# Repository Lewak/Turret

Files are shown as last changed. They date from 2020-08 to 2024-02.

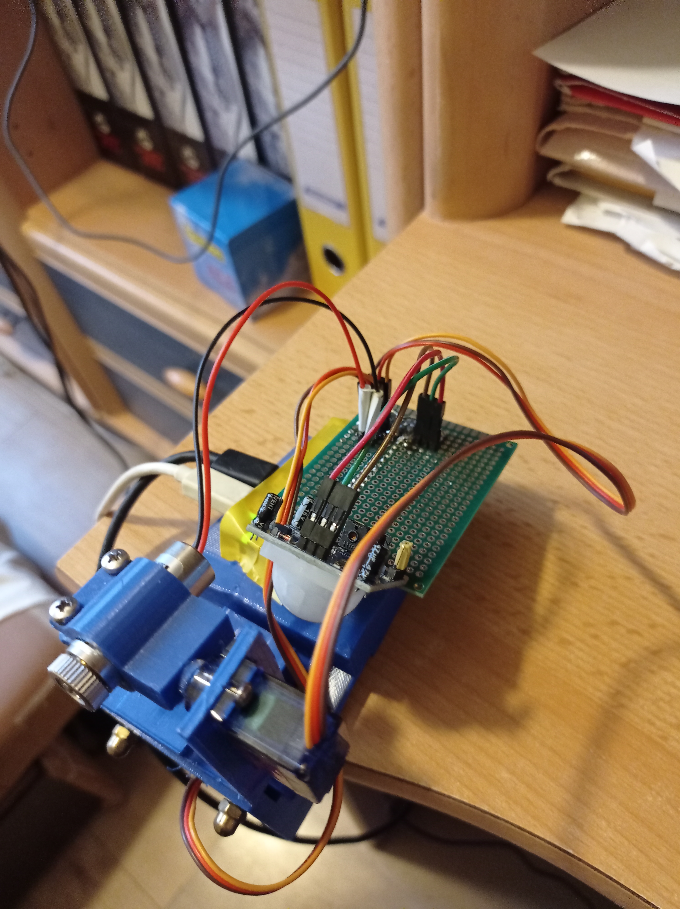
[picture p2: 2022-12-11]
Schemas/raspberry + peripherals assembly.jpg

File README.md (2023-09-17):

# INSTRUKCJA
## vol.1 RASPBERRY JAKO ETHERNET GADGET
1. Podłączyć raspberry za pomocą kabla USB (DO PORTU USBIN nie USB POWER!)
2. Sprawdzić w menadżerze urządzeń czy jest wykrywany jako usb ethernet gadget. Jak tak, przejść do kroku 6
3. Pobrać sterownik usb ethernet gadget (Acer Incorporated. - Other hardware - USB Ethernet/RNDIS Gadget) stąd: 
	https://www.catalog.update.microsoft.com/Search.aspx?q=USB%20RNDIS%20Gadget
4. Wypakować pobrane archiwum, kliknąć ppm na RNDIS.inf i wybrać install
5. Wejść w menadżer urządzeń, odłączyć i podłączyć RPi, żeby zobaczyć jako co jest wykrywane - może to być np. port COM. Wybrać to urządzenie, 
	update driver, browse my computer, let me pick from a list.., have disk, wybrać RNDIS.inf. Sprawdzić czy teraz jest wykrywany, 
	jak nie to można się popłakać i zawołać mazura.
6. Spróbować połączyć się za pomocą komendy ssh, adres IP można zdobyć poprzez ipconfig albo spróbować użyć: ssh pi@raspberrypi.local (hasło to raspberry)
7. Mozna zainstalowac sterownik Bonjour, by moc używać nazwy .local w IDE (możliwe że niepotrzebne)
8. By uruchomić internet na raspberry. Należy wejść w windows panel sterownia, network and sharing -> change adapter settings
	(old: ethernet settings -> change adapter settings) 
	wybrać AKTUALNE DZIAŁAJĄCE POŁĄCZENIE INTERNETOWE (NIE IP RASPBERRY) -> properties -> settings ->sharing -> w obu checkboxach zaznaczyć allow 
	i wybrać Ethernet gadget RPi
9. Powinno działać 

## vol.2 DŹWIĘK I IO
1. Plik do dźwięku znajduje sie w: /etc/asound.conf
2. Plik autostartu z komendami uruchamianymi przy boocie to /etc/rc.local (komenda sudo pigpiod -t 0)
		
## vol.3 PROCEDURA URUCHAMIANIA TURRETA
1. Wpisać login i password w deployment w file->settings->deployment: login:pi hasło: raspberry
2. Prawy przycisk na pliki programu i deployment->send to raspberrypi

## vol.4 PROCEDURA URUCHAMIANIA PŁYKI ENDERA
1. Zainstalować środowisko kombatybilne z Arduino (np Visual Studio Code z pluginem). 
2. Zainstalować boardy Sanguino
3. Przed uploadem ustawić port COM, ustawić płytkę Sanguino z procesorem Atmega1284 16Mhz.

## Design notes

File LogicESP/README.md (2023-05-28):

# Konfiguracja środowiska
1. Zainstaluj sterownik: https://www.silabs.com/developers/usb-to-uart-bridge-vcp-drivers?tab=downloads, zakładka CP210x VCP Windows
2. Podłącz płytkę przez USB C
3. W Visual Studio Code zainstaluj plugin "Arduino". Za pomocą `Ctrl + Shift + P` wywołuj komendy do komunikacji z płytką.
4. Arduino: Board Manager -> Additional URLs -> Add -> wpisz https://raw.githubusercontent.com/espressif/arduino-esp32/gh-pages/package_esp32_index.json i zatwierdź -> wyłącz okno Board Manager
5. Arduino: Board Config -> ESP32 Dev Module (esp32), Core Debug Level: Verbose
6. Arduino: Select Serial Port -> COM4

# Podłączanie układu
Powinno być tak:

lol

Uwaga, przed podłączeniem zasilania upewnić się, że:
+ nie ma zwarć
+ napięcia są dobrze podłączone, tj. 12V, 5V i 3.3V idą dokładnie tam gdzie powinny i nigdzie indziej
+ plusy i minusy nie są odwrotnie
+ najpierw należy podłączyć zasilanie do komputera, a potem zasilanie zewnętrzne 12V

W trakcie pracy:
+ Nie wolno odłączać silników ani jakichkolwiek innych komponentów
+ Jakiekolwiek modyfikacje powinny być wykonywane po odłączeniu zasilania

# Uruchamianie kodu
1. Arduino: Upload
2. Gdy płytka jest zorientowana tak, że kabel USB wchodzi do niej od dołu, na prawo od kabla znajduje się przycisk flash, a na lewo reset. Gdy w konsoli output stanie na "Serial port COM4", wciśnij i przytrzymaj flash, następnie wciśnij reset, puść reset, puść flash (kolejność ma znaczenie). Jeśli upload się nie powiód:
    + może być zły port - powinno być COM4
    + warto odłączyć usb od komputera i wpiąć ponownie

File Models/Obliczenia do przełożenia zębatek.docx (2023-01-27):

Byłoby dobrze, gdyby ramię było w stanie skręcić o α=90^(∘) w ciągu t=0.25 s . Oznacza to, że musi mieć takie przyspieszenie kątowe ϵ , że w czasie t przez połowę czasu będzie przyspieszać, przez drugą połowę czasu zwalniać, a w łącznym czasie przebędzie kąt π/2 , czyli α=1/2∙t∙1/2ϵt=1/4ϵt^2 , stąd ϵ=(4α)/(t^2) .

Aby obliczyć moment bezwładności ramion wokół osi pionowej (ruch lewo-prawo) przyjmujemy, że każde z ramion można przybliżyć jako masę punktową m=3 kg zawieszoną w odległości d=25 cm od osi, stąd I_(vertical) =2∙1/2∙m∙d^2 =md^2 .

Moment bezwładności wokół osi poziomej (ruch góra-dół) przybliżamy za pomocą dwóch cylindrów o masie m=3 kg i promieniu r=25 cm obracających się wokół swojej osi, czyli również I_(horizontal) =2∙1/2∙m∙r^2 =mr^2 . Ponieważ ze względu na gabaryty wieżyczki d=r , mamy I=I_(horizontal) =I_(vertical) .

Moment siły wynosi więc M_(arms) =Iϵ=md^2 ∙(4α)/(t^2) .

Moment obrotowy silnika Nema 17 wynosi M_(nema) =2000 gcm=2000∙g∙10^(-5) Nm=0.1962 Nm .

Przełożenie zębatek musi więc wynosić na obu osiach:

(M_(arms))/(M_(nema))=3kg∙(0.25m)^2 ∙4∙π/2∙1/((0.25s)^2)∙1/(0.1962 Nm)=96

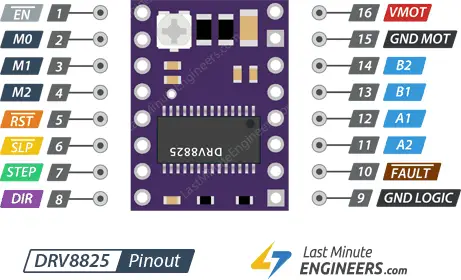
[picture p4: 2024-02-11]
Schemas/Pinout - DRV8825.png

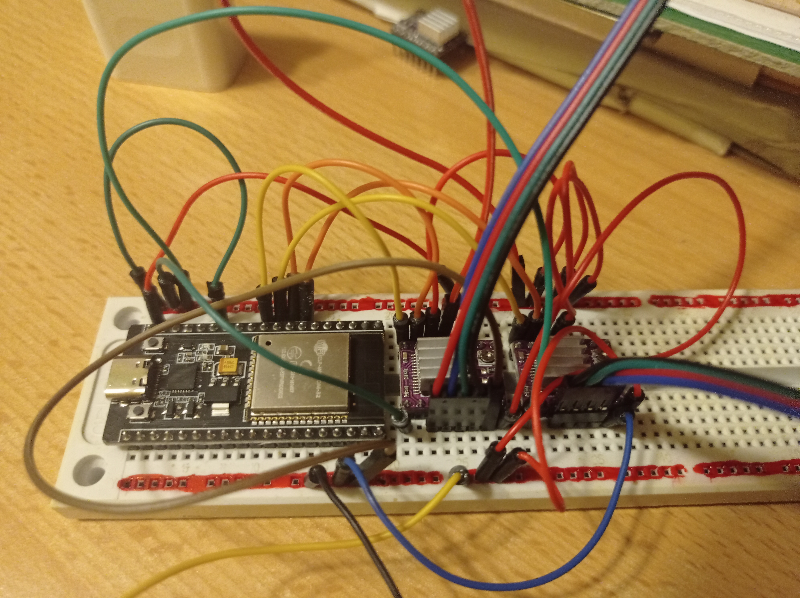
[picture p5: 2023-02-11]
Schemas/esp + 2 steppers.jpg

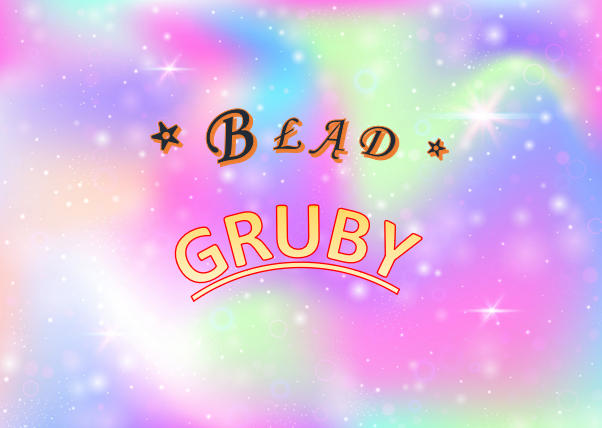
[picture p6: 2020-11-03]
Schemas/Błąd Gruby.png

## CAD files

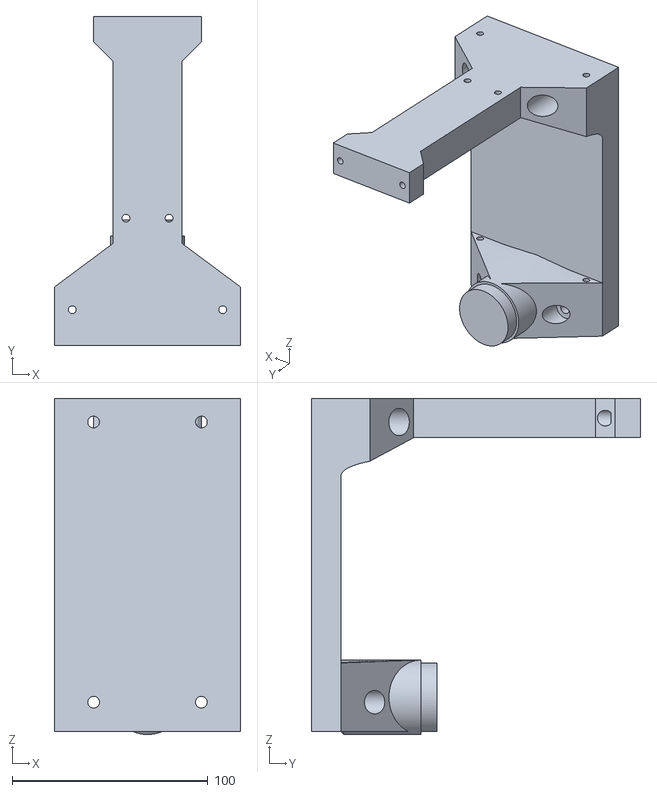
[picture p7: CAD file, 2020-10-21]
Models/turret_assembly/Design Accelerator/main_stand_lower_half.stl
95.0 x 168.0 x 171.5

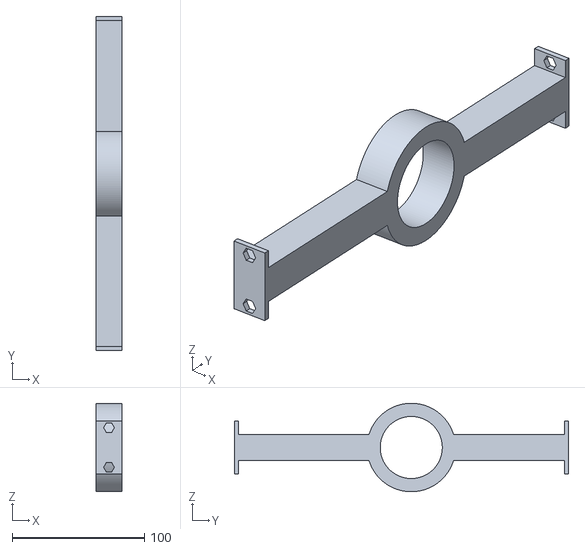
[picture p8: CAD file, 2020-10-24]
Models/turret_assembly/Design Accelerator/pylon.stl
20.0 x 253.0 x 67.0

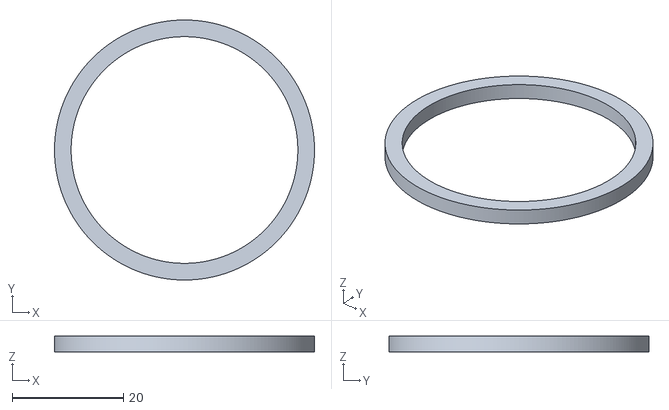
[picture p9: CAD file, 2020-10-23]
Models/turret_assembly/Design Accelerator/Swash_distance.stl
46.8 x 46.8 x 2.80

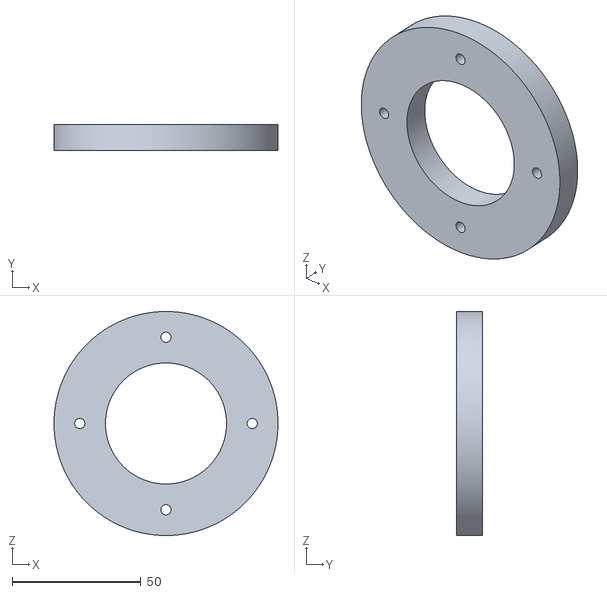
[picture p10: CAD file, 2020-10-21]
Models/turret_assembly/Design Accelerator/horizontal_lower_bearing_holder.stl
87.0 x 10.0 x 87.0

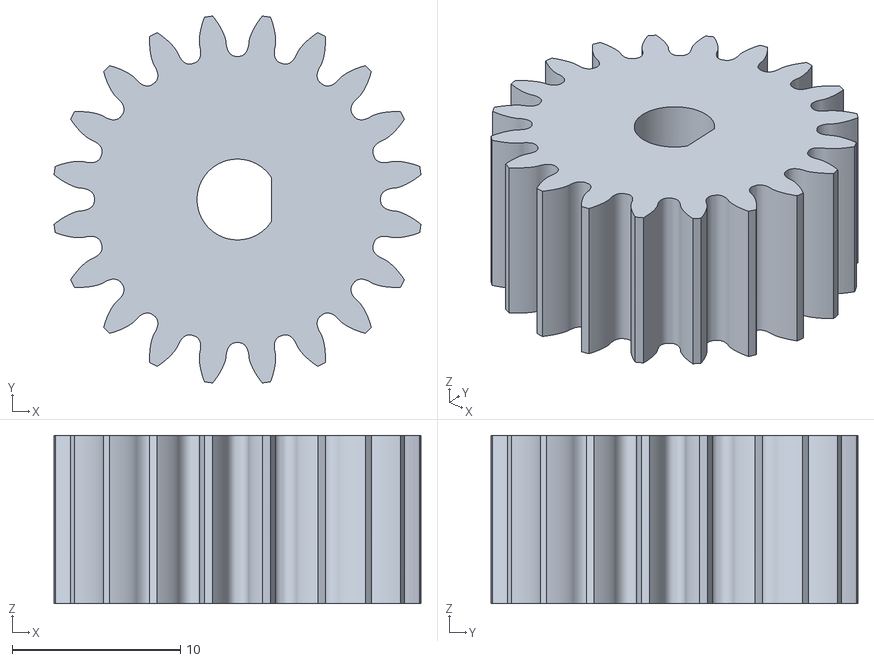
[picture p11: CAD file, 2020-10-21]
Models/turret_assembly/Design Accelerator/vertical_axis_small_gear.stl
21.8 x 21.8 x 10.0

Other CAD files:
Models/Gimbal.dwg
Models/camera_holder.ipt
Models/pylon-hal-bearing-holder.ipt
Models/pylon_actuator_holder.ipt
Models/pylon_actuator_holder_jaw.ipt
Models/raspberry_holder.ipt
Models/servo_holder.ipt
Models/step_motor/Flecha 17HS4401 v3.ipt
Models/step_motor/INF TECNICA 2 v1.ipt
Models/step_motor/Nema 17 Motor a Pasos 17HS4401.iam
Models/step_motor/Part10.ipt
Models/step_motor/Pines v2.ipt
Models/step_motor/Tornillo v2.ipt
Models/turret_assembly.iam
Models/turret_assembly/Design Accelerator/Spur Gear11.ipt
Models/turret_assembly/Design Accelerator/Spur Gear21.ipt
Models/turret_assembly/Design Accelerator/Spur Gears1.iam
Models/turret_assembly/Design Accelerator/Swash_distance.ipt
Models/turret_assembly/Design Accelerator/big_actuator_holder.ipt
Models/turret_assembly/Design Accelerator/horizontal_axis_big_gear.ipt
Models/turret_assembly/Design Accelerator/horizontal_axis_hal_gearr.ipt
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

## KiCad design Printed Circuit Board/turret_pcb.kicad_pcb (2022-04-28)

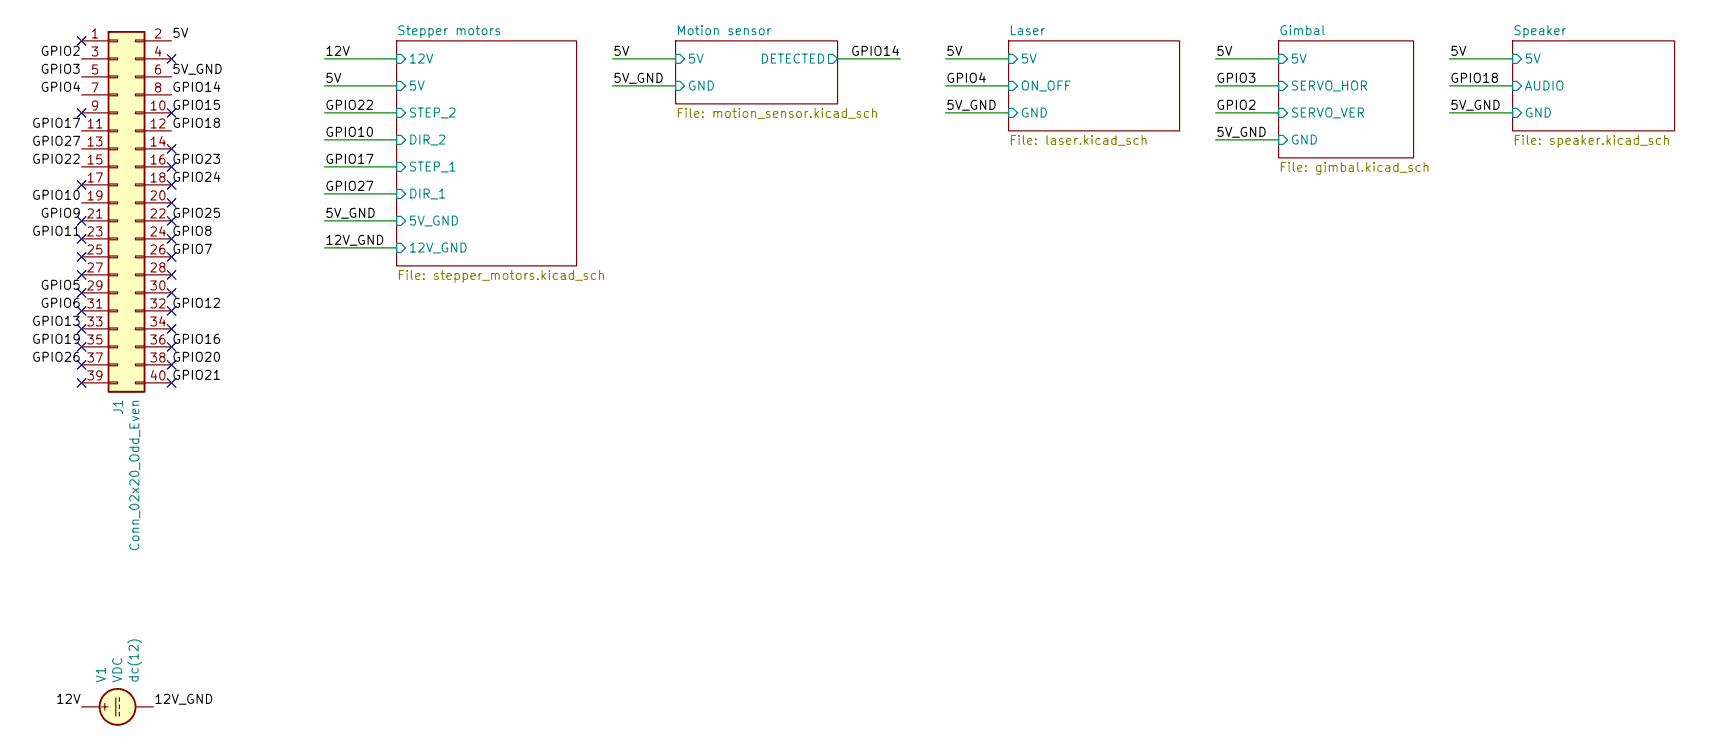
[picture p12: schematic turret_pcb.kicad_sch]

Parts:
J1: Conn_02x20_Odd_Even; PinSocket_2x20_P2.54mm_Vertical
V1: VDC; Banana_Jack_2Pin

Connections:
/5V: J1.2; also elsewhere on the board
/5V_GND: J1.6; also elsewhere on the board
/12V: V1.1; also elsewhere on the board
/12V_GND: V1.2; also elsewhere on the board
/GPIO2: J1.3; also elsewhere on the board
/GPIO3: J1.5; also elsewhere on the board
/GPIO4: J1.7; also elsewhere on the board
/GPIO5: J1.29
/GPIO6: J1.31
/GPIO7: J1.26
/GPIO8: J1.24
/GPIO9: J1.21
/GPIO10: J1.19; also elsewhere on the board
/GPIO11: J1.23
/GPIO12: J1.32
/GPIO13: J1.33
/GPIO14: J1.8; also elsewhere on the board
/GPIO15: J1.10
/GPIO16: J1.36
/GPIO17: J1.11; also elsewhere on the board
/GPIO18: J1.12; also elsewhere on the board
/GPIO19: J1.35
/GPIO20: J1.38
/GPIO21: J1.40
/GPIO22: J1.15; also elsewhere on the board
/GPIO23: J1.16
/GPIO24: J1.18
/GPIO25: J1.22
/GPIO26: J1.37
/GPIO27: J1.13; also elsewhere on the board

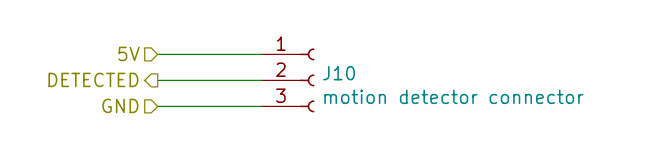
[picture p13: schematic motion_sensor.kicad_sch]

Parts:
J10: motion detector connector; PinHeader_1x03_P2.54mm_Vertical

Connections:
/5V: J10.1; also elsewhere on the board
/5V_GND: J10.3; also elsewhere on the board
/GPIO14: J10.2; also elsewhere on the board

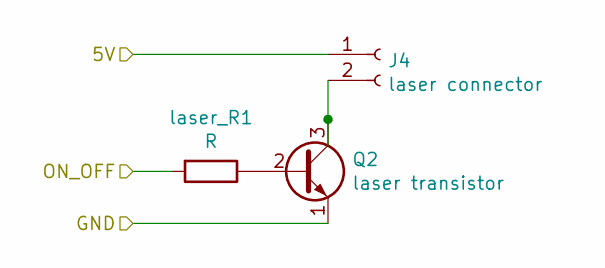
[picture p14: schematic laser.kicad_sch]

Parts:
J4: laser connector; PinHeader_1x02_P2.54mm_Vertical
Q2: laser transistor; TO-39-3
laser_R1: R; R_1206_3216Metric

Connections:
/5V: J4.1; also elsewhere on the board
/5V_GND: Q2.1 (E); also elsewhere on the board
/GPIO4: laser_R1.2; also elsewhere on the board
unnamed: J4.2, Q2.3 (C)
unnamed: Q2.2 (B), laser_R1.1

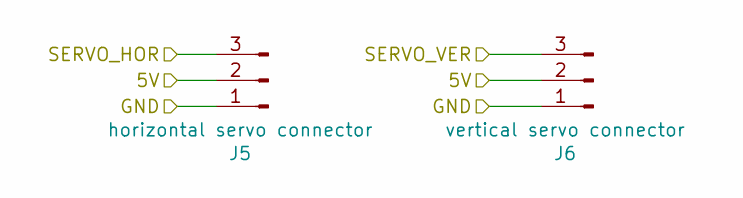
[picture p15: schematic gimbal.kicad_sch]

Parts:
J5: horizontal servo connector; PinHeader_1x03_P2.54mm_Vertical
J6: vertical servo connector; PinHeader_1x03_P2.54mm_Vertical

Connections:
/5V: J5.2, J6.2; also elsewhere on the board
/5V_GND: J5.1, J6.1; also elsewhere on the board
/GPIO2: J6.3; also elsewhere on the board
/GPIO3: J5.3; also elsewhere on the board

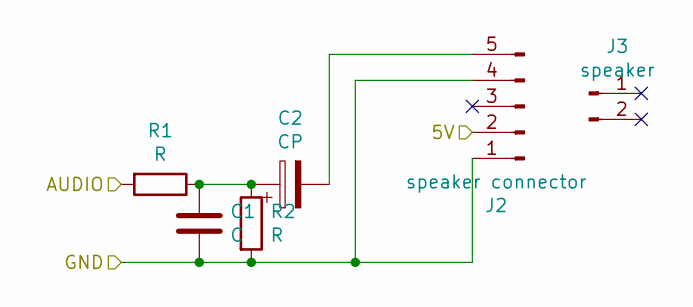
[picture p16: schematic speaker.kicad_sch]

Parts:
C1: C; C_Disc_D4.7mm_W2.5mm_P5.00mm
C2: CP; C_Radial_D6.3mm_H5.0mm_P2.50mm
J2: speaker connector; PinHeader_1x05_P2.54mm_Vertical
J3: speaker; PinHeader_1x02_P2.54mm_Vertical
R1: R; R_1206_3216Metric_Pad1.30x1.75mm_HandSolder
R2: R; R_1206_3216Metric

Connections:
/5V: J2.2; also elsewhere on the board
/5V_GND: C1.2, J2.1, J2.4, R2.2; also elsewhere on the board
/GPIO18: R1.2; also elsewhere on the board
unnamed: C1.1, C2.1, R1.1, R2.1
unnamed: C2.2, J2.5

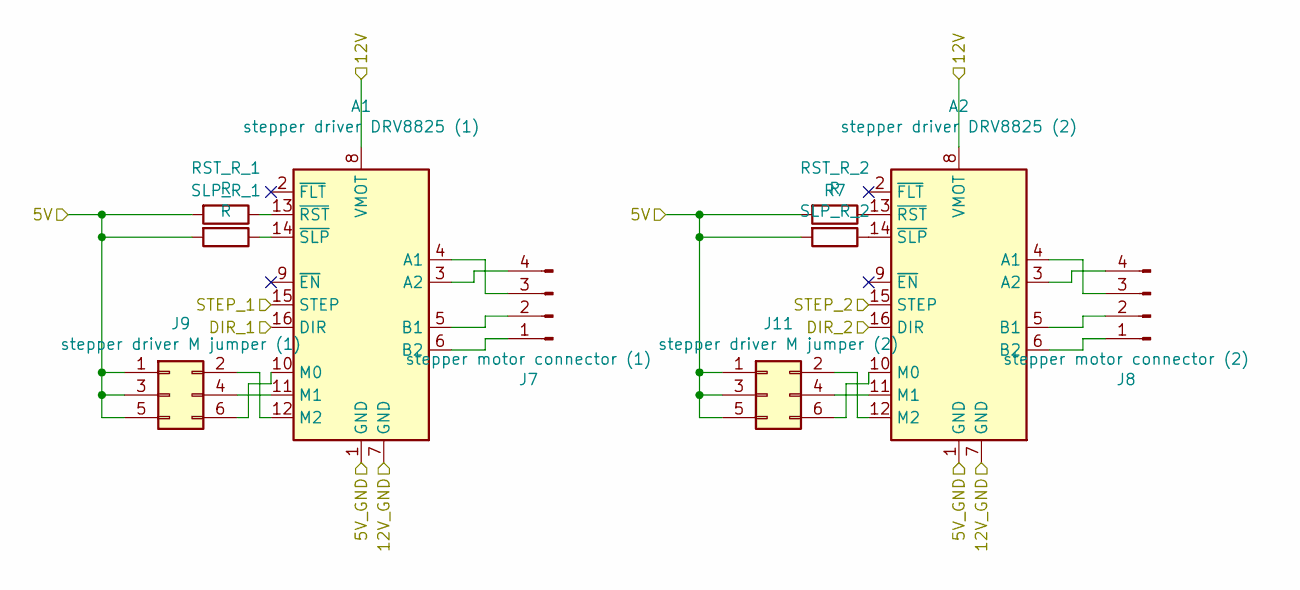
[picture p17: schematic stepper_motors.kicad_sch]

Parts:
A1: stepper driver DRV8825 (1); Pololu_Breakout-16_15.2x20.3mm
A2: stepper driver DRV8825 (2); Pololu_Breakout-16_15.2x20.3mm
J7: stepper motor connector (1); PinHeader_1x04_P2.54mm_Vertical
J8: stepper motor connector (2); PinHeader_1x04_P2.54mm_Vertical
J9: stepper driver M jumper (1); PinSocket_2x03_P2.54mm_Vertical
J11: stepper driver M jumper (2); PinSocket_2x03_P2.54mm_Vertical
R7: SLP_R_2; R_1206_3216Metric
RST_R_1, RST_R_2: R; R_1206_3216Metric
SLP_R_1: R; R_1206_3216Metric

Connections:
/5V: J9.1, J9.3, J9.5, J11.1, J11.3, J11.5, R7.2, RST_R_1.2, RST_R_2.2, SLP_R_1.2; also elsewhere on the board
/5V_GND: A1.1 (GND), A2.1 (GND); also elsewhere on the board
/12V: A1.8 (VMOT), A2.8 (VMOT); also elsewhere on the board
/12V_GND: A1.7 (GND), A2.7 (GND); also elsewhere on the board
/GPIO10: A2.16 (DIR); also elsewhere on the board
/GPIO17: A1.15 (STEP); also elsewhere on the board
/GPIO22: A2.15 (STEP); also elsewhere on the board
/GPIO27: A1.16 (DIR); also elsewhere on the board
unnamed: A1.3 (A2), J7.4
unnamed: A1.4 (A1), J7.3
unnamed: A1.5 (B1), J7.2
unnamed: A1.6 (B2), J7.1
unnamed: A1.10 (M0), J9.6
unnamed: A1.11 (M1), J9.4
unnamed: A1.12 (M2), J9.2
unnamed: A1.13 (~RST), RST_R_1.1
unnamed: A1.14 (~SLP), SLP_R_1.1
unnamed: A2.3 (A2), J8.4
unnamed: A2.4 (A1), J8.3
unnamed: A2.5 (B1), J8.2
unnamed: A2.6 (B2), J8.1
unnamed: A2.10 (M0), J11.6
unnamed: A2.11 (M1), J11.4
unnamed: A2.12 (M2), J11.2
unnamed: A2.13 (~RST), RST_R_2.1
unnamed: A2.14 (~SLP), R7.1

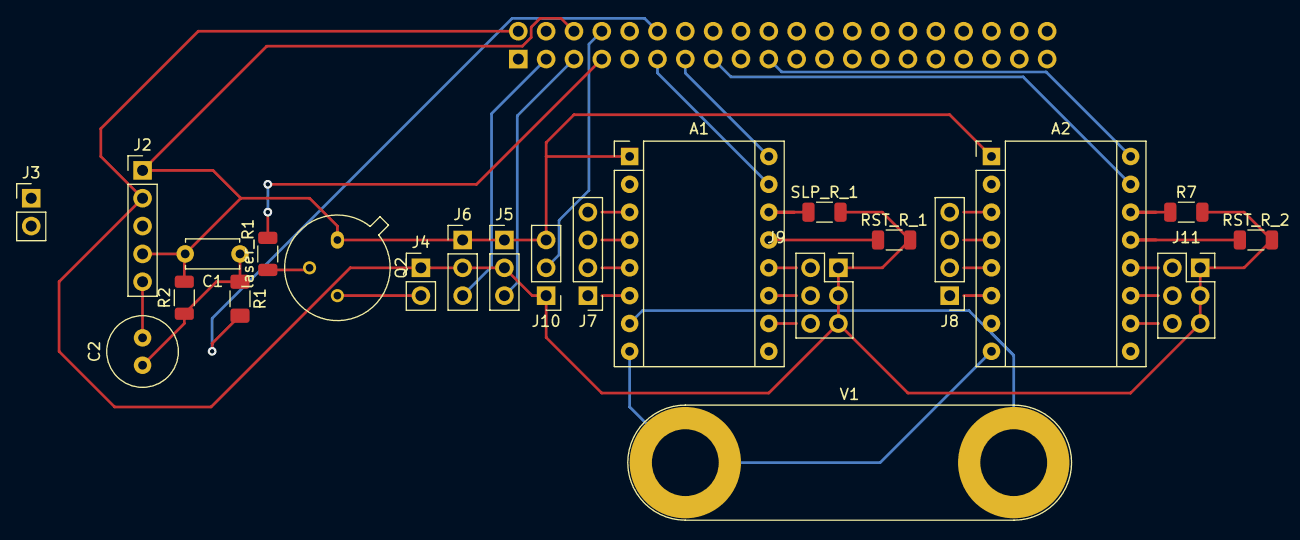
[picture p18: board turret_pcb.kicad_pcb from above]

Board: 2 copper layers, 24 parts (1 on the bottom side), 35 nets.

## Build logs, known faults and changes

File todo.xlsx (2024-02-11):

Silniki krokowe | Skonfigurować nową płytkę arduino+drv8825 zamiast ender3
 | Potestować konfigurację z czujnikiem Halla (coś w stylu PID)
 | Poeksperymentować z trybami pracy driverów w silnikach
 | Podłączyć esp + raspberry przez Serial
 | Programowanie | ESP: cleanup kodu, użycie hala i dwóch silników Raspberry: uzgodnić układ współrzędnych (środek, orientacja); refactor pathGenerator; klasa do obsługi arm-gimbala
 | Przelutować pajęczaka na płytkę
 | Przeprojektować model w inventorze, by obsługiwał silniki i Halla | zębatki wokół osi pionowej się rozjechały
 |  | constrainy na obrót wokół osi pionowej są zrąbane
 |  | czujniki hala na oś pionową i poziomą
 |  | miejsce na przewody ciśnieniowe
 |  | duża zębatki mogą być ucięte do połowy (180* ruchu zamiast 360*)
 | Przełożenie zębatek wymaga aktualizacji | nie bardzo wiadomo jakiego przełożenia użyć - do sprawdzenia z realnym obciążeniem
Lutowanie | Naprawić potencjometr w lutownicy
Audio | Uszkodzony układ audio u Piotera
 | Użyć nowych odzyskanych głośników
 | Dodać wzmacniacz | później
 | Dodać głośnik basowy do pary | później
Siłowniki i hydrostatyka
Kamera
Działka
Obudowa | PCB integrujące wszystkie płytki i komponenty
 | miejsce na płytki w modelu
 | Przemyślenie prowadzenia kabli między komponentami
 | Zrobić dystans na silnik poziomy
Naprawy | Naprawić/przeprojektować mechanizm celowania laserem.

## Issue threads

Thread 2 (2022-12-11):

Redesign spur gears to accomodate different reduction ratios

Lewak, 2022-12-11:
Current reduction ratio (1:10) is definitely too much. It would be a good idead to design alternate version of these parts. Modular/parametric design would be prefered here

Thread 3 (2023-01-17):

Repair of main soldering iron used in this project.

Lewak, 2023-01-17:
It came to our attention, that the soldering iron that our main electronic engineer uses, is in simple words, "fucked" (PL. "zjebana"). To further our attempts at assembling prototype boards, it needs to be fixed. Our enginner will need another soldering iron to fix the broken one. Let's hope it doesn't became a while (true) loop if this second soldering iron breaks.

boberrs, 2023-01-17:
Please forward the issue to IT-Support team, they should get us new equipment delivered and ready to go. Changing status to "invalid", our technicians need not to be bothered by malfunctioning devices.

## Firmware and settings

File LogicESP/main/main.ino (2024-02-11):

#include <Arduino.h>
#include <vector>
#include <string>
#include "utils.h"
#include "hal.h"
#include "serialCommunication.h"
#include "serialCommunication1.h"
using namespace std;

#define LED 2
#define STEP_X 32
#define STEP_Y 33
#define DIR_X 25
#define DIR_Y 26
#define M0_Y 12
#define M1_Y 14
#define M2_Y 27
#define MOT_ANG_MIN_DEG 5
#define MOT_ANG_MAX_DEG 175

int positionCounter = 0; // temp
int motorSpeed = 15;
int desiredAngle = 90;

void setup()
{
    serialInit();
    serial1Init();
    halInit();
    pinMode(LED, OUTPUT);
    pinMode(M0_Y, OUTPUT);
    pinMode(M1_Y, OUTPUT);
    pinMode(M2_Y, OUTPUT);
    pinMode(STEP_X, OUTPUT);
    pinMode(STEP_Y, OUTPUT);
    pinMode(DIR_X, OUTPUT);
    pinMode(DIR_Y, OUTPUT);

    digitalWrite(DIR_X, HIGH);
    digitalWrite(DIR_Y, HIGH);
    digitalWrite(M0_Y, HIGH);
    digitalWrite(M1_Y, HIGH);
    digitalWrite(M2_Y, HIGH);
}

void loop()
{
    double angle = mockReadAngle();
    serial1Read([](string code, vector<int> parameters){
        if (code == "SET")
        {
            desiredAngle = clampValue(parameters[0], MOT_ANG_MIN_DEG, MOT_ANG_MAX_DEG);
        }
    });
       
    if ((desiredAngle < angle - 0.2) || (desiredAngle > angle + 0.2))
    {
        if (desiredAngle - angle > 0)
        {
            digitalWrite(DIR_Y, LOW);
            positionCounter++;
        }
        else
        {
            digitalWrite(DIR_Y, HIGH);
            positionCounter--;
        }
        digitalWrite(STEP_X, HIGH);
        digitalWrite(STEP_Y, HIGH);
        delayMicroseconds(motorSpeed);
        digitalWrite(STEP_X, LOW);
        digitalWrite(STEP_Y, LOW);
        delayMicroseconds(motorSpeed);
    }
}

double mockReadAngle()
{
    float gearRatio = 10;
    float stepsPerRevolution = 200;
    float microsteps = 32;
    return positionCounter / gearRatio * (360.0 / (stepsPerRevolution * microsteps)) + 90;
}

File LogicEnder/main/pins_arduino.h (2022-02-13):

// ATMEL ATMEGA644/ATMEGA1284 / SANGUINO
//
//                        +---\/---+
//            (D 0) PB0  1|        |40  PA0 (AI 0 / D31)
//            (D 1) PB1  2|        |39  PA1 (AI 1 / D30)
//       INT2 (D 2) PB2  3|        |38  PA2 (AI 2 / D29)
//        PWM (D 3) PB3  4|        |37  PA3 (AI 3 / D28)
//     SS PWM (D 4) PB4  5|        |36  PA4 (AI 4 / D27)
//       MOSI (D 5) PB5  6|        |35  PA5 (AI 5 / D26)
//       MISO (D 6) PB6  7|        |34  PA6 (AI 6 / D25)
//        SCK (D 7) PB7  8|        |33  PA7 (AI 7 / D24)
//                  RST  9|        |32  AREF
//                  VCC 10|        |31  GND
//                  GND 11|        |30  AVCC
//                XTAL2 12|        |29  PC7 (D 23)
//                XTAL1 13|        |28  PC6 (D 22)
//       RX0 (D 8)  PD0 14|        |27  PC5 (D 21) TDI
//       TX0 (D 9)  PD1 15|        |26  PC4 (D 20) TDO
//  INT0 RX1 (D 10) PD2 16|        |25  PC3 (D 19) TMS
//  INT1 TX1 (D 11) PD3 17|        |24  PC2 (D 18) TCK
//       PWM (D 12) PD4 18|        |23  PC1 (D 17) SDA
//       PWM (D 13) PD5 19|        |22  PC0 (D 16) SCL
//       PWM (D 14) PD6 20|        |21  PD7 (D 15) PWM
//                        +--------+

#ifndef pins_arduino_h
#define pins_arduino_h

#define PA0 (31)
#define PA1 (30)
#define PA2 (29)
#define PA3 (28)
#define PA4 (27)
#define PA5 (26)
#define PA6 (25)
#define PA7 (24)

#define PB0 (0)
#define PB1 (1)
#define PB2 (2)
#define PB3 (3)
#define PB4 (4)
#define PB5 (5)
#define PB6 (6)
#define PB7 (7)

#define PC0 (16)
#define PC1 (17)
#define PC2 (18)
#define PC3 (19)
#define PC4 (20)
#define PC5 (21)
#define PC6 (22)
#define PC7 (23)

#define PD0 (8)
#define PD1 (9)
#define PD2 (10)
#define PD3 (11)
#define PD4 (12)
#define PD5 (13)
#define PD6 (14)
#define PD7 (15)


#define SD_SS (PA0)
#define LCD_SCK (PA1)
#define EXT_A2 (PA2)
#define LCD_CS (PA3)
#define Beeper (PA4)
#define ZENABLE (PA5)
#define BEDTEMP (PA6)
#define ENDTEMP (PA7)

#define E_DIR (PB0)
#define E_STEP (PB1)
#define Z_DIR (PB2)
#define Z_STEP (PB3)
#define FAN (PB4)
#define MOSI (PB5)
#define MISO (PB6)
#define SCLK (PB7)

#define Encoder_Button (PC0)
#define LCD_MOSI (PC1)
#define X_STOP (PC2)
#define Y_STOP (PC3)
#define Z_STOP (PC4)
#define X_DIR (PC5)
#define Y_STEP (PC6)
#define Y_DIR (PC7)

#define AIFO (PD0)
#define AOFI (PD1)
#define Encoder_A (PD2)
#define Encoder_B (PD3)
#define Hotbed (PD4)
#define Hotend (PD5)
#define XYEENABLE (PD6)
#define X_STEP (PD7)

#endif

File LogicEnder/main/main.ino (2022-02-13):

#include <AccelStepper.h>
#include <MultiStepper.h>


#include "pins_arduino.h"
#define acceleration 2000
#define deceleration 1000
#define max_speed 6000
#define full_rotation 3200
#define first_delay 80
int actual_speed = 1000;
int target_speed = 80000;

void setup() 
{
    float acc_dec_ratio = (acceleration/deceleration);

    Serial.begin(9600);
    pinMode(XYEENABLE, OUTPUT);
    pinMode(X_DIR, OUTPUT);
    pinMode(X_STEP, OUTPUT);
    pinMode(Y_DIR, OUTPUT);
    pinMode(Y_STEP, OUTPUT);

    digitalWrite(XYEENABLE, LOW);   
    digitalWrite(X_DIR, LOW);
    digitalWrite(X_STEP, HIGH);
    digitalWrite(Y_DIR, LOW);
    digitalWrite(Y_STEP, HIGH);
    ramp(1,80000);

}

void loop() 
{
    // delay();
    // PORTD |= B10000000;
    // PORTC |= B01000000;
    // // digitalWrite(X_STEP, LOW);
    // // digitalWrite(Y_STEP, LOW);
    // delayMicroseconds(15);
    // PORTD &= B01111111;
    // PORTC &= B10000000;
    delayMicroseconds(15);

    // digitalWrite(X_STEP, HIGH);
    // digitalWrite(Y_STEP, HIGH);
}


void ramp(int actual_speed, int target_speed){

    int ramp_count = abs(target_speed - actual_speed)/10;
    int final_delay = 1000000 / target_speed;
    int actual_delay = 1000000  / actual_speed;
    const int target_spedded = 80000;
    const int start = 80;
    const int end = 1000000 / 80000;
    const int diff = (first_delay - end);

    for(float i = 0; i < 1; i+=0.00001)
    {
        delayMicroseconds(first_delay - i * diff);
        PORTD |= B10000000;
        PORTC |= B01000000;
        delayMicroseconds(first_delay - i * diff);
        PORTD &= B01111111;
        PORTC &= B10000000;
    }

}

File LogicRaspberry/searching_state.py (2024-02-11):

from peripherals import Peripherals
from serial_interface import Serial
from audio_interface import SfxType
from random_path_generator import randomPathGenerator
from random_path_generator import wobbleGenerator
from state_machine import State
from finish_searching_state import FinishSearchingState
import random
import math


class SearchingState(State):
    def __init__(self):
        initAngle = random.uniform(0, 360)
        initialXPosition = 90 + math.sin(initAngle) * 40
        initialYPosition = 90 + math.cos(initAngle) * 40
        self.wobbler = wobbleGenerator()
        self.pathGenerator = randomPathGenerator(90, 90, initialXPosition, initialYPosition)

    def routine(self) -> State:
        positionX, positionY, isFinished = next(self.pathGenerator)
        Peripherals.gimbal.setPosition(positionX, positionY + next(self.wobbler))
        Serial.sendMessage("SET " + str(positionY + next(self.wobbler)) + "\n")

        if isFinished:
            return FinishSearchingState()
        else:
            return self

    def enter(self) -> None:
        Peripherals.audio.playRandomEffect(SfxType.SEARCHING)
        Peripherals.laser.turnOn()

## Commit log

2020-07-25 Laser class completed. Added clause to turn it off at the end of execution
2020-07-25 Servo and Gimbal class completed
2020-07-29 Repo structure change
    [Gimbal.dwg, costs.xlsx]
2020-08-04 audio samples
2020-08-04 Added parts used in testing phase
    [camera_holder.ipt, raspberry_holder.ipt, servo_holder.ipt]
2020-08-06 Added some new exciting features, Added GPIOinterface and motion sensor
2020-08-31 Audio interface refactor & costs
    [costs.xlsx]
2020-10-06 Inventor turret assembly
    [horizontal_axis_big_gear.ipt, turret_assembly.iam, vertical_axis_bigl_gear.ipt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]
2020-10-09 Turret main mechanism upgrade
    [main_stand_lower_half.ipt, main_stand_upper_half.ipt, pylon.ipt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]
2020-10-10 Main mechanism decomposition
    [Flecha 17HS4401 v3.ipt, INF TECNICA 2 v1.ipt, Nema 17 Motor a Pasos 17HS4401.iam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]
2020-10-10 assembly fix
    [horizontal_axis_motor_metal_holder.ipt, horizontal_lower_bearing_holder.ipt, turret_assembly.iam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]
2020-10-12 main_stand_upper_half loft fixed
    [main_stand_upper_half.ipt, turret_assembly.iam]
2020-10-21 Lower stand fixed. Added STL models to print
    [horizontal_lower_bearing_holder.stl, main_stand_lower_half.ipt, main_stand_lower_half.stl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]
2020-10-21 Lowered the ammount of PLA used.
    [horizontal_lower_bearing_holder.ipt, main_stand_lower_half.ipt, main_stand_lower_half.stl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]
2020-10-23 Swash distance added, fixed bearing mount
    [Swash_distance.ipt, Swash_distance.stl, horizontal_axis_motor_metal_holder.ipt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]
2020-10-24 actuators holders
    [big_actuator_holder.ipt, costs.xlsx, horizontal_axis_big_gear.ipt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]
2020-10-26 Models improvements, assembly constraints fixed
    [big_actuator_holder.ipt, big_actuator_holder_exported_half_1.ipt, big_actuator_holder_exported_half_2.ipt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]
2020-10-27 small fixes in models
    [big_actuator_holder.ipt, big_actuator_holder_exported_half_1.ipt, big_actuator_holder_exported_half_2.ipt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]
2020-10-29 assembly in blueprint
    [costs.xlsx]
2020-11-01 collinear actuator holders
    [big_actuator_holder.ipt, big_actuator_holder_exported_half_1.ipt, big_actuator_holder_exported_half_2.ipt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]
2020-11-03 Błąd Gruby
    [big_actuator_holder.ipt, big_actuator_holder_exported_half_1.ipt, horizontal_axis_big_gear.ipt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]
2020-11-04 models small fixes
    [big_actuator_holder_exported_half_1.ipt, big_actuator_holder_exported_half_2.ipt, small_actuator_holder.ipt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]
2021-02-05 costs update
    [costs.xlsx]
2021-02-09 The costs are piling up
    [costs.xlsx]
2021-02-17 pneumatic costs
    [costs.xlsx]
2021-02-18 PCB scheme only
    [costs.xlsx, turret_pcb.kicad_pcb, turret_pcb.sch]
2021-02-20 PCB separate schemas for components
    [gimbal.sch, laser.sch, motion_sensor.sch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]
2021-02-20 PCB: using m0, m1, m2 in stepper motors
    [stepper_motors.sch]
2021-02-21 PCB: physical board prototype
    [gimbal.sch, laser.sch, motion_sensor.sch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]
2021-02-22 PCB physical board
    [gimbal.sch, laser.sch, motion_sensor.sch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]
2021-03-06 Added first power button implementation
2021-06-27 robotronik costs
    [costs.xlsx]
2021-08-28 First version of Arduino side board program
    [costs.xlsx]
2022-04-28 KiCAD version updated 5 -> 6
    [gimbal.kicad_sch, gimbal.sch, laser.kicad_sch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]
2022-07-10 Update instruction for Raspberry Pi SSH connection
2022-07-10 Add laser part number to costs files
    [costs.xlsx]
2022-12-10 Project cleanup
    [todo.xlsx]
2022-12-11 Informational and organizational update
    [costs.xlsx, todo.xlsx]
2023-01-15 project structure cleanup
    [todo.xlsx]
2023-01-27 Gears ratio calculations
    [todo.xlsx]
2023-02-11 ESP board initial setup
    [todo.xlsx]
2023-03-18 initial protocol setup for ESP
    [costs.xlsx, todo.xlsx]
2023-05-28 Continuing working on C++ ESP32 code for motor driving.
2023-07-02 improvements and cleanup for assembly
    [Swash_distance.ipt, big_actuator_holder.ipt, horizontal_axis_big_gear.ipt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]
2023-07-30 WIP: Inventor models for hal holders
    [Spur Gear11.ipt, Spur Gear21.ipt, Spur Gears1.iam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]
2023-09-17 HAL sensors holders added to assembly
    [horizontal_axis_hal_gearr.ipt, pylon-hal-bearing-holder.ipt, todo.xlsx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]
2024-02-11 Succesful connection between RsPI and ESP device. First implementation of stepper motor movement in gimbal achieved.
    [costs.xlsx, pylon_actuator_holder.ipt, todo.xlsx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]
